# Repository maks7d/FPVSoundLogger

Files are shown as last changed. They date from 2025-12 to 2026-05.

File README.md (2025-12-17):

# FPVSoundLogger
A DIY RP2040-Zero based onboard audio recorder for FPV drones. It uses a MEMS mic and SD card module to capture sound, automatically triggered by Betaflight arming via PinioBox. Recordings match DJI goggles video length for seamless editing. Includes hardware design, MicroPython code, and examples.

###### Enjoy this project or find it useful? Feel free to buy me a coffee ☕ to support its development. 

## Project Background

I first started experimenting with the excellent and promising [OpenIPC](https://github.com/openipc) project, driven by my love for tinkering, hacking, and coding. The idea of building an open FPV video system was incredibly appealing.
But after many tests, the freeze issues and limited range eventually convinced me to switch to DJI for reliable everyday flying.
(But I promise — I’ll come back to OpenIPC!)

The DJI O4 Air Unit provides fantastic onboard video recordings.
But (because there's always a “but”), it still doesn’t record audio. And audio truly adds something special — whether for aggressive FPV flying or even some cinematic flights.

So I wanted a solution that would be simple/lightweight/inexpensive and capable of recording high‑quality audio and perfectly* synchronized with DJI recordings.
This project is the result of that idea.

##### Démo


Play

## Features
- Autonomous module
- Work with [Betaflight](https://github.com/betaflight/betaflight)/[INAV](https://github.com/iNavFlight/inav) 
- Enable/disable recording
- Auto record using arm/disarm trigger
- Audio/video share the same duration*

## Prerequisites

- A flight controller running **[Betaflight](https://github.com/betaflight/betaflight)**/**[INAV](https://github.com/iNavFlight/inav)** with at least two available Pinio outputs
- A transmitter (TX) capable of assigning **AUX channels** (EdgeTX, OpenTX, etc.)
- A stable **3.3V** output on the flight controller and a **common ground**
- A free **switch** or similar to toggle recording modes
- Basic soldering tools for connecting power, ground, and signal wires and plenty of flux — <u>***flux is life***</u>

## How It Works

- Power up the drone — In **Disable** mode module's LED **Red** blinking 🔴
- Use one of your TX switches to **Enable** recording mode — the LED now blinks **Green** 🟢
- **Arm**: the module immediately starts **writing audio data** to the SD card, and the LED now blinks **Blue** 🔵
- **Once disarmed** — whether after a normal end of flight or a dramatic crash — the module **stops recording** and finalizes the audio file with the proper header
- Remove the SD card and retrieve the **WAV file** that matches the exact flight duration
- Import the audio into your favorite video editor and drop it on the timeline — it syncs effortlessly with the DJI footage !
> **⚠️ Fine-tuning tip:** Due to DJI's camera initialization delay after arming, 
> you may need to offset the audio track by **0.5-2 seconds** in your editor. 

**Format:** `rec_XXXX_MM-SS.wav`
- 🔵 **Index (XXXX)**: Auto-incremented counter (0001, 0002, 0003...)
- 🟡 **Duration (MM-SS)**: Recording length in minutes and seconds

FilesDurations

## Architecture / Hardware Overview

### Components

|  | INMP441 | RP2040-Zero | SD Card SPI Module |
| - | :---: | :---: | :---: |
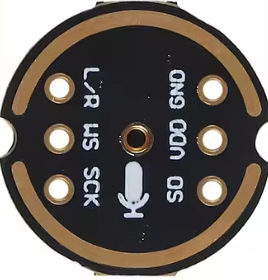
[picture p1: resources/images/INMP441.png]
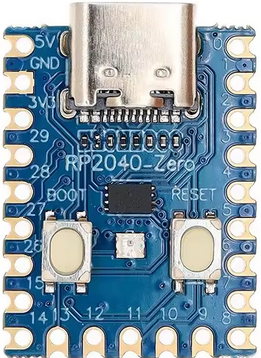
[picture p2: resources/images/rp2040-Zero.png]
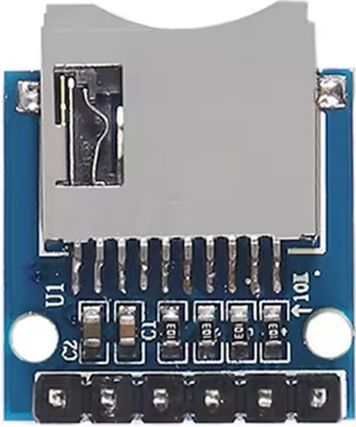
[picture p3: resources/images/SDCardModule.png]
| | |  |  |
| Description | The INMP441 is a compact digital MEMS microphone that outputs audio through an I²S interface.It delivers low‑noise, high‑quality audio capture with a built‑in amplifier and ADC | The Raspberry Pi Pico uses the RP2040 dual‑core ARM Cortex‑M0+ microcontroller running at up to 133 MHz with 264 KB RAM and 2 MB flash.It offers rich connectivity like I²C, SPI, UART, PWM, ADC, and powerful PIO blocks for custom protocols.Compact, low‑cost, and easy to program in **MicroPython** or C/C++.| Micro SD TF Card Memory Shield Module provides an easy way to add microSD storage to microcontrollers.It uses an onboard card socket and level shifting for safe 3.3 V–5 V operation.Ideal for large dataqqsets via SPI. |
| Size | 12x14mm | 18x24.5mm | 18x21mm |
| Weight | 0.36gr | 1.66gr | 1.46gr |
| AliExpress | [INMP441](https://www.aliexpress.com/item/1005007889064664.html?spm=a2g0o.order_list.order_list_main.142.32325e5blt8IZ0) | [RP20240-Zero](https://www.aliexpress.com/item/1005007650325892.html?spm=a2g0o.order_list.order_list_main.147.32325e5blt8IZ0) | [SD TF Module](https://www.aliexpress.com/item/1005005591145849.html?spm=a2g0o.order_list.order_list_main.152.32325e5blt8IZ0) |

### Wiring
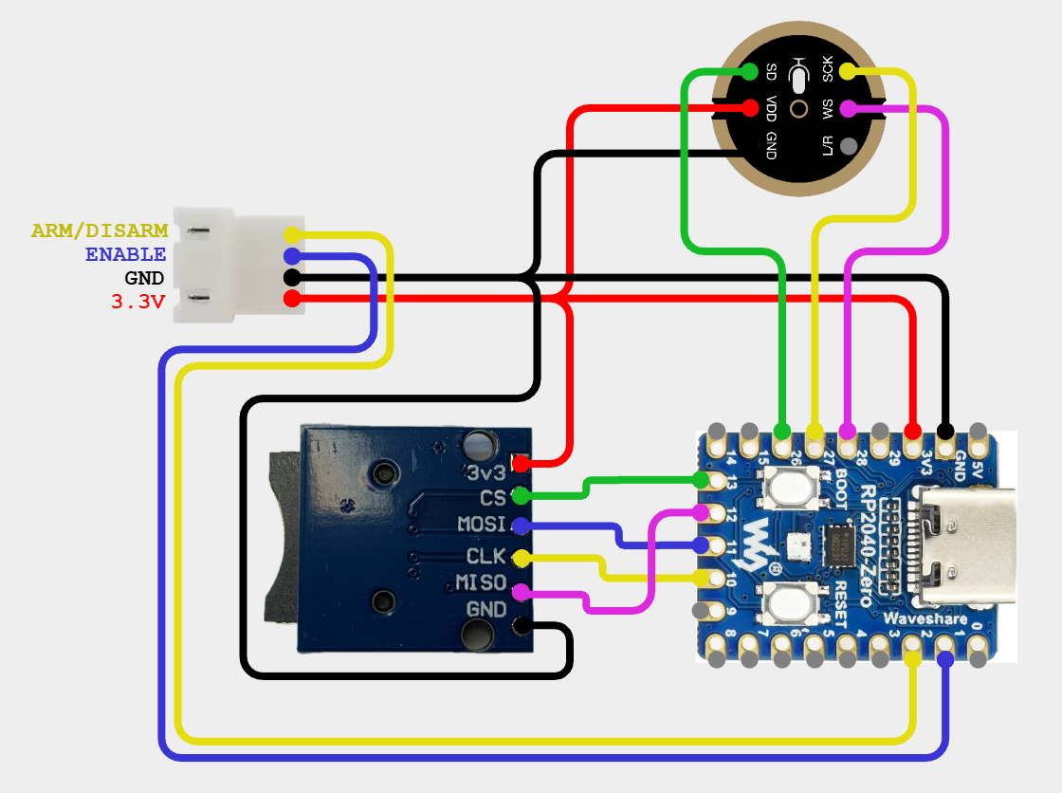
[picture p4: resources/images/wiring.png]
WIRING


### Alternatives
An alternative is to use the FC’s 5 V rail to power the Pi Pico. The SD Card SPI module can convert data signals to 3.3 V levels, allowing it to use the Pi Pico’s 5 V rail. However, according to the [INMP441](resources/datasheet/INMP441.pdf) datasheet, the maximum supply voltage must not exceed 3.63 V, so **you must power it from the Pi Pico’s 3.3 V rail**.

## Build 

In the interest of keeping things lightweight and considering the very low current required for the system to operate, 28‑AWG silicone cable is more than sufficient, and you shouldn’t add more than 1 g to the whole setup.I cut and glued a small foam circle — the kind you find at the bottom of FC/ESC boxes, as dense as possible — to make a windscreen/pop filter.

Be careful not to get any glue into the microphone’s input opening.To keep everything in place, I used a ridiculously heavy piece of heat‑shrink tubing to “thermal‑zipper” the whole thing, along with a bit of hot glue (B7000 is obviously the best option, though hard to find) to secure the small 4‑pin JST connector against the assembly.

In my rough version installed in my Jeno 5", the module weighs about 10 g, but it’s definitely possible to do much better.

A voltage spike can cause parasitic artifacts in the recording. I haven’t tested this yet, but as mentioned in the [INMP441](resources/datasheet/INMP441.pdf) datasheet it is recommended to use a small 0.1 µF ceramic capacitor between VDD and GND.

##### Examples
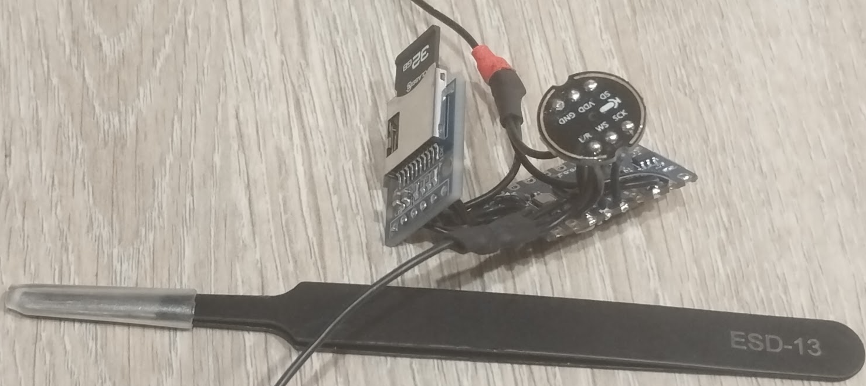
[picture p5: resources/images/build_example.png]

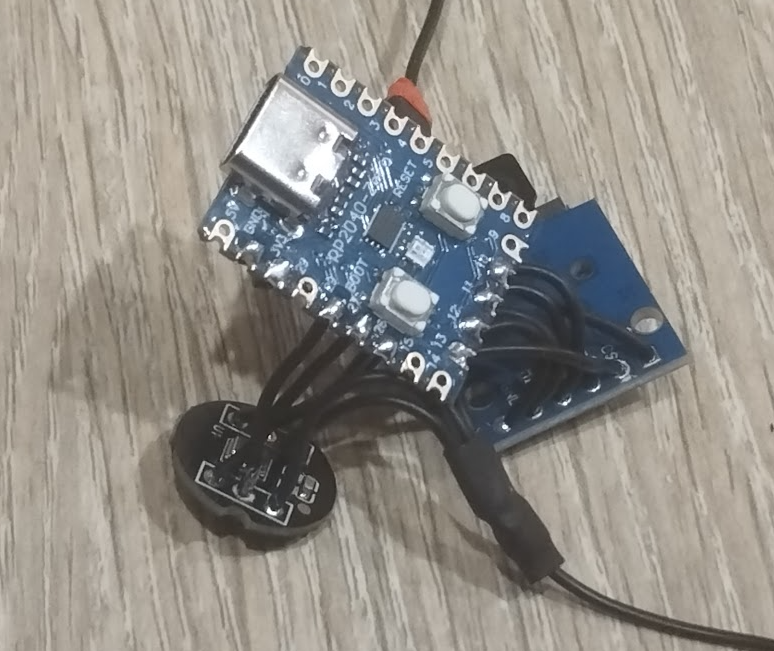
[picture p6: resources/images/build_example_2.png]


## Installation & Configuration

### Pi Pico: Flashing MicroPython on an RP2040 with Thonny

##### 1. Install Thonny
- Download and install [Thonny](https://thonny.org/) from the official website.  
- Open [Thonny](https://thonny.org/).

##### 2. Put the RP2040 board into bootloader mode
- Plug in the board **while holding the BOOTSEL button**.  
- Release the button once connected: the board should appear as a USB drive named **RPI-RP2**.

##### 3. Install MicroPython from [Thonny](https://thonny.org/)
- In Thonny, go to:  
  **Tools → Options… → Interpreter**  
- Select:  
  **MicroPython (Raspberry Pi Pico / RP2040)**  
- Click **Install or update MicroPython**.  
- Select your **RPI-RP2** device.  
- Start the installation.

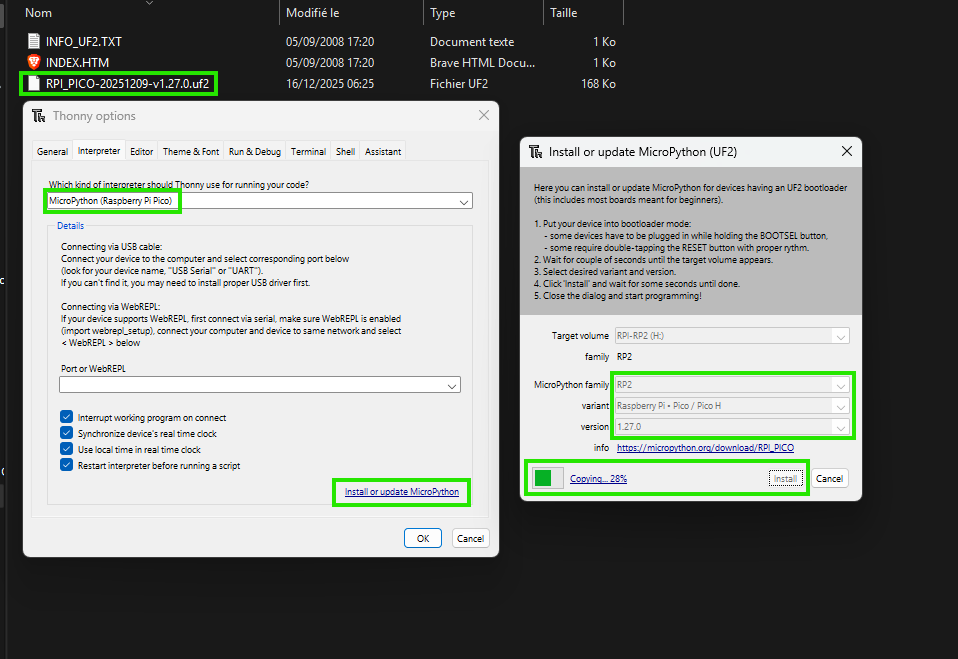
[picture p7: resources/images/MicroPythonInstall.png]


##### 4. Automatic restart
The board will reboot with MicroPython installed.  
[Thonny](https://thonny.org/) should now display a `>>>` prompt.

##### 5. Quick test
Type:

```python
print(f"WE ARE {'fpv'.upper()}")
```

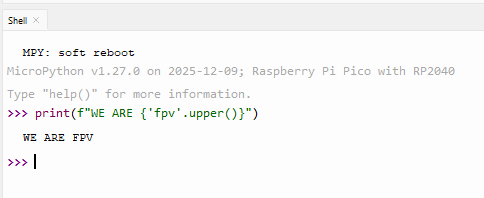
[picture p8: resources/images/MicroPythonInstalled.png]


##### 6. Project files to upload
```
├── main.py                    # Main application (auto-runs on boot)
   └── lib/
       ├── sdcard.py              # SD card driver
       └── fpv_sound_logger.py    # Core logger class
```

- In Thonny, go to **View > Files**
- In your computer's file panel (left side), navigate to your project folder
- Select the `lib` folder
- Right-click → **"Upload to /"**
- Then select `main.py`
- Right-click → **"Upload to /"**
- Thonny will upload the entire structure automatically

> **Note:** This method preserves the folder structure. The `lib` folder and its contents will be uploaded correctly.
<p align="left">
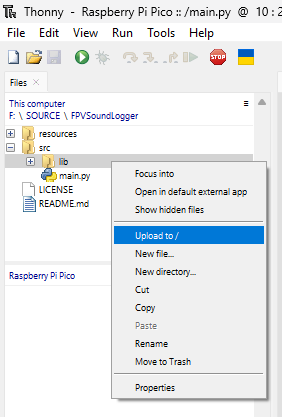
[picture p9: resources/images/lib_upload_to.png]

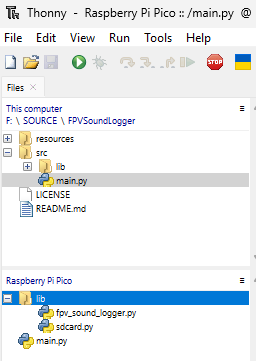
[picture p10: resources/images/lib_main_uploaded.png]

</p>

### TX && Betaflight configuration

All you need to know about Betaflight's Pinio && PinioBox can be found [here](https://www.betaflight.com/docs/wiki/guides/current/Pinio-and-PinioBox), I also got some excellent advice from Betaflight’s [official discord](https://discord.betaflight.com/)

- You'll need to configure AUX channel on your TX to Enable/Disable recording

    > I configured it to use the center position of an three-position switch mapped to AUX6 on my Radiomaster Pocket running on EdgeTX.

- Provide a **common ground** from the flight controller to the module, along with a clean **3.3V** or [5V supply](#Alternatives)

    > On my JHEMCU GF20F722, I used the 3.3V rail that was originally intended for a DSM receiver.

- Configure your flight controller’s Pinio outputs using CLI to deliver the required logic levels:

    - One Pinio controls record enable/disable

    - The second Pinio follows the arm/disarm sequence to automatically start and stop recording.

    > [...]
    > 
    > resource pinio 1 B10          # remap RX3 pad
    > 
    > resource pinio 2 B11          # remap TX3 pad
    > 
    > set pinio_config = 1,129,1,1  # High level for _pinio 1_ and inverted for _pinio 2_
    > 
    > set pinio_box = 40,0,255,255  # ID 40 mean BOXUSER1 and ID 0 Arm/Disarms

- Configure a new mode for USER1

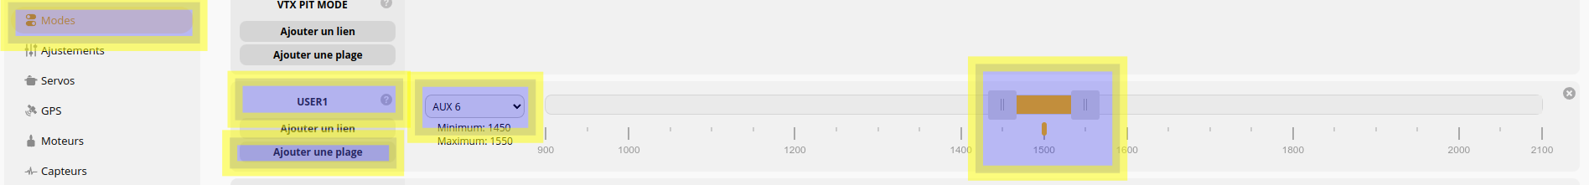
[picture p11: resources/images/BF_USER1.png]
test


### For testing purposes

Even if the 3.3 V or 5 V rail used to power the recorder is active while [Betaflight](https://github.com/betaflight/betaflight) is connected via USB, you still won’t be able to start the recording. The [Betaflight](https://github.com/betaflight/betaflight) safety flags will prevent the drone from arming.

Because of this, even with the ***MOTOR_STOP*** option enabled in the Motors tab, the brushless motors may still start spinning. As a result, you will always have motor or propeller noise in your recordings — never any silence. And if you need to speak into the microphone, **be careful**… or make sure to shout loud enough! ^^

###### TODO
A lot ...!?

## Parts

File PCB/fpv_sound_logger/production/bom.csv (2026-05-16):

Designator | Footprint | Quantity | Value | LCSC Part #
C1, C10, C11, C14, C2, C3, C4, C5, C6, C7 | 0603 | 10 | 100n
C12, C13 | 0603 | 2 | 15p
C15, C17 | 0603 | 2 | 10u
C19, C8, C9 | 0603 | 3 | 1u
CN1 | CONN-SMD_4P-P1.00_SM04B-SRSS-TB-LF-SN | 1 | SM04B-SRSS-TB(LF)(SN)
D1, D2 | SOT95P280X145-5M | 2 | MAX40203AUK+T
IC1 | SOIC127P790X216-8N | 1 | W25Q128JVSIQ
J2 | CUI_MSD-4-A | 1 | MSD-4-A
LED1 | INS66TFT5R5G5B | 1 | IN-S66TFT5R5G5B
LED2 | LED_LTST-C171_LTO-M | 1 | LTST-C171KRKT
MIC1 | MIC-TH_BD6.0-P1.90-D0.4-L-FD_GMI6050P-2CXXDB | 1 | ~
R1, R2 | 0603 | 2 | 27
R10, R11, R13, R3, R9 | 0603 | 5 | 1k
R12, R17, R18, R19, R20 | 0603 | 5 | 10k
R14 | 0603 | 1 | 2k2
R5, R6 | 0603 | 2 | 5k1
S1, S2 | B3U-1000P | 2 | B3U-1000P
U3 | SOT95P280X145-5N | 1 | TLV75533PDBVR
U4 | QFN40P700X700X90-57N | 1 | SC0914_13_
USB1 | USB-C-SMD_TYPE-C-6PIN-2MD-073 | 1 | TYPE-C 16PIN 2MD(073)
Y1 | ABM8272T3 | 1 | ABM8-272-T3

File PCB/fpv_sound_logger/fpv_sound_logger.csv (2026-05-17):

Reference | Qty | Value | DNP | Exclude from BOM | Exclude from Board | Footprint | Datasheet | Manufacturer_Part_Number | Supplier | Supplier Part | Manufacturer
C1,C2,C3,C4,C5,C6,C7,C10,C11,C14 | 10 | 100n |  |  |  | Capacitor_SMD:C_0603_1608Metric |  | CL10B104KB8NNNC | LCSC | C1591 | Samsung Electro-Mechanics
C8,C9,C19 | 3 | 1u |  |  |  | Capacitor_SMD:C_0603_1608Metric |  | CL10B105KA8NNNC | LCSC | C29936 | Samsung Electro-Mechanics
C12,C13 | 2 | 15p |  |  |  | Capacitor_SMD:C_0603_1608Metric |  | CL10C150JB8NNNC | LCSC | C1644 | Samsung Electro-Mechanics
C15,C17 | 2 | 10u |  |  |  | Capacitor_SMD:C_0603_1608Metric |  | CL10A106MQ8NNNC | LCSC | C1691 | Samsung Electro-Mechanics
CN1 | 1 | SM04B-SRSS-TB(LF)(SN) |  |  |  | fpv_sound_logger:CONN-SMD_4P-P1.00_SM04B-SRSS-TB-LF-SN |  | SM04B-SRSS-TB(LF)(SN) | LCSC | C160404 | JST
D1,D2 | 2 | MAX40203AUK+T |  |  |  | fpv_sound_logger:SOT95P280X145-5M |  | MAX40203AUK+T | LCSC | C2653639 | MAXIM
IC1 | 1 | W25Q128JVSIQ |  |  |  | fpv_sound_logger:SOIC127P790X216-8N |  | W25Q128JVSIQ | LCSC | C113767 | Winbond
J2 | 1 | MSD-4-A |  |  |  | fpv_sound_logger:CUI_MSD-4-A |  | MSD-4-A | LCSC | C22367949 | CUI Devices
LED1 | 1 | IN-S66TFT5R5G5B |  |  |  | fpv_sound_logger:INS66TFT5R5G5B |  | 19-337/R6GHBHC-A01/2T | LCSC | C264519 | EVERLIGHT
LED2 | 1 | LTST-C171KRKT |  |  |  | fpv_sound_logger:LED_LTST-C171_LTO-M |  | LTST-C171KRKT | LCSC | C284871 | LITEON
MIC1 | 1 |  |  |  |  | fpv_sound_logger:MIC-TH_BD6.0-P1.90-D0.4-L-FD_GMI6050P-2CXXDB | https://atta.szlcsc.com/upload/public/pdf/source/20180613/C233951_CF3F103FE3546E5F8FCD1BC0597FF08F.pdf | GMI6050P-36db | LCSC | C233939 | INGHAi
R1,R2 | 2 | 27 |  |  |  | Resistor_SMD:R_0603_1608Metric |  | ERJ3EKF27R0V | LCSC | C403127 | PANASONIC
R3,R9,R10,R11,R13 | 5 | 1k |  |  |  | Resistor_SMD:R_0603_1608Metric |  | ERJ3EKF1001V | LCSC | C118155 | PANASONIC
R5,R6 | 2 | 5k1 |  |  |  | Resistor_SMD:R_0603_1608Metric |  | ERA3AEB512V | LCSC | ERA3AEB512V | PANASONIC
R12,R17,R18,R19,R20 | 5 | 10k |  |  |  | Resistor_SMD:R_0603_1608Metric |  | ERJUP3F1002V | LCSC | ERJUP3F1002V | PANASONIC
R14 | 1 | 2k2 |  |  |  | Resistor_SMD:R_0603_1608Metric |  | ERJ3EKF1001V | LCSC | C118155 | PANASONIC
S1,S2 | 2 | B3U-1000P |  |  |  | fpv_sound_logger:B3U-1000P | https://www.omron.com/ecb/products/pdf/en-b3u.pdf | B3U-1000P | LCSC | C231329 | OMRON
TP1,TP2,TP3,TP4 | 4 | TestPoint | DNP |  |  | TestPoint:TestPoint_Pad_D1.0mm
U3 | 1 | TLV75533PDBVR |  |  |  | fpv_sound_logger:SOT95P280X145-5N |  | TLV75533PDBVR | LCSC | C404027 | TI
U4 | 1 | SC0914_13_ |  |  |  | fpv_sound_logger:QFN40P700X700X90-57N |  | RP2040 | LCSC | C2040 | Raspberry Pi
USB1 | 1 | TYPE-C 16PIN 2MD(073) |  |  |  | fpv_sound_logger:USB-C-SMD_TYPE-C-6PIN-2MD-073 | https://item.szlcsc.com/datasheet/TYPE-C%252016PIN%25202MD(073)/2901843.html | TYPE-C 16PIN 2MD(073) | LCSC | C2765186 | SHOU HAN
Y1 | 1 | ABM8-272-T3 |  |  |  | fpv_sound_logger:ABM8272T3 | https://abracon.com/datasheets/ABM8-272-T3.pdf | ABM8-272-T3 | LCSC | C20625731 | ABRACON

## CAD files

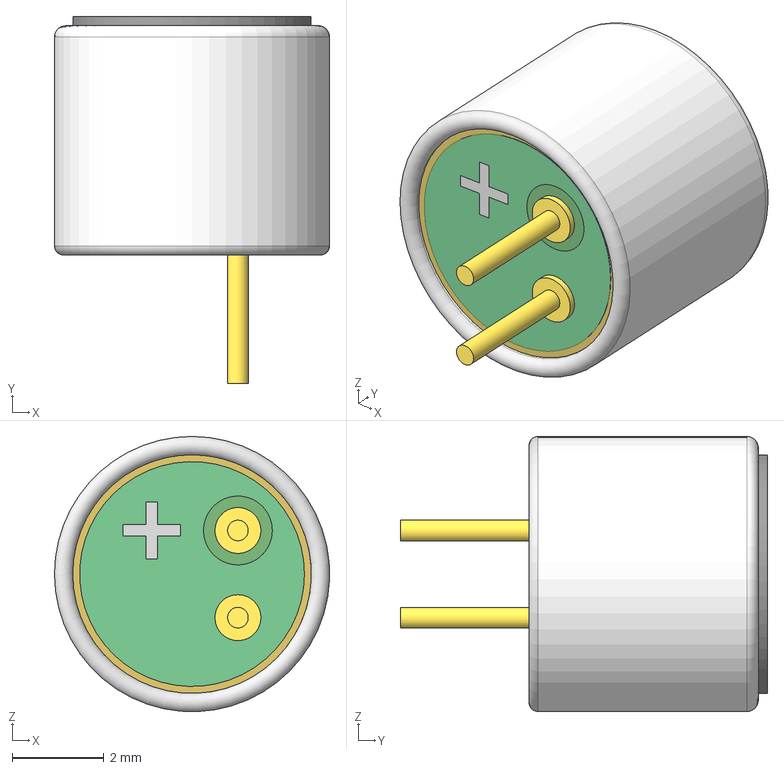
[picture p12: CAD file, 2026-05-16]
PCB/3D/POM-5038P-C3310-R.STEP
6.00 x 8.00 x 6.00 mm

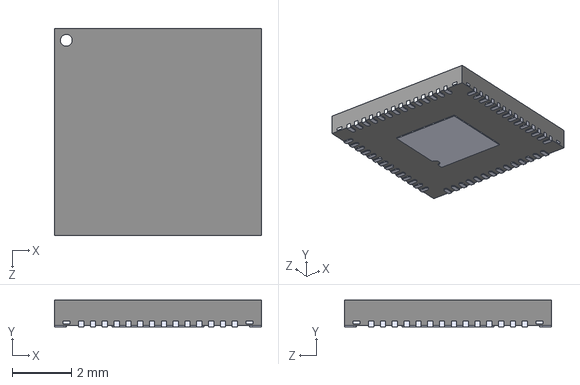
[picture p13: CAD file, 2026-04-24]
PCB/3D/SC0914_13_.step
7.00 x 0.9 x 7.00 mm

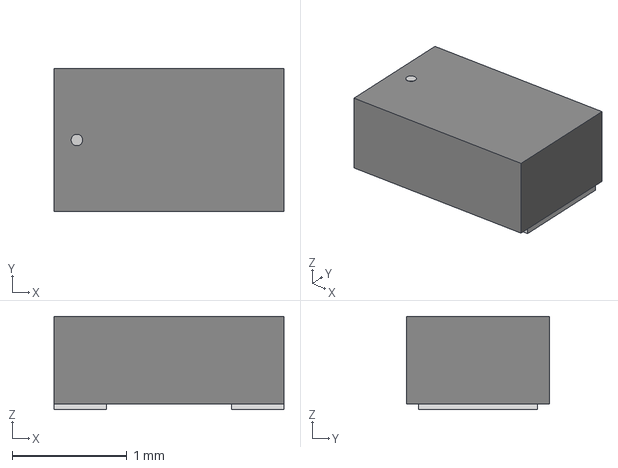
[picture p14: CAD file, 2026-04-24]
PCB/3D/LED_LTST-C171_LTO.step
2.01 x 1.24 x 0.815 mm

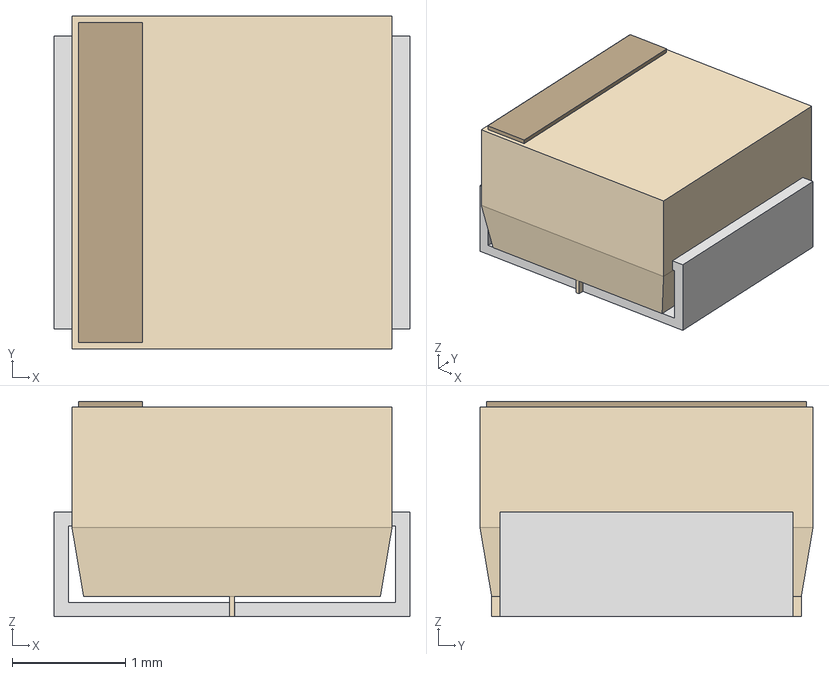
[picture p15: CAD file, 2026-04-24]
PCB/3D/LED_X01-GS08_VIS.step
3.15 x 2.95 x 1.91 mm

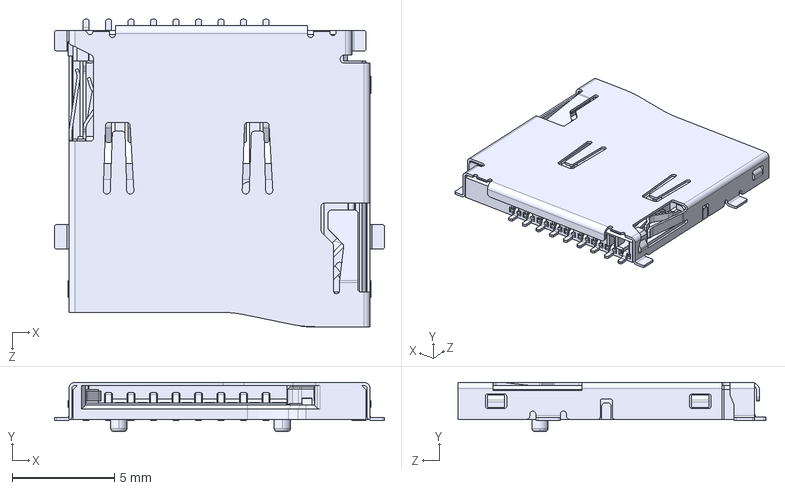
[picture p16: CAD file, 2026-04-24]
PCB/3D/MSD-4-A.step
16.1 x 2.40 x 15.0 mm

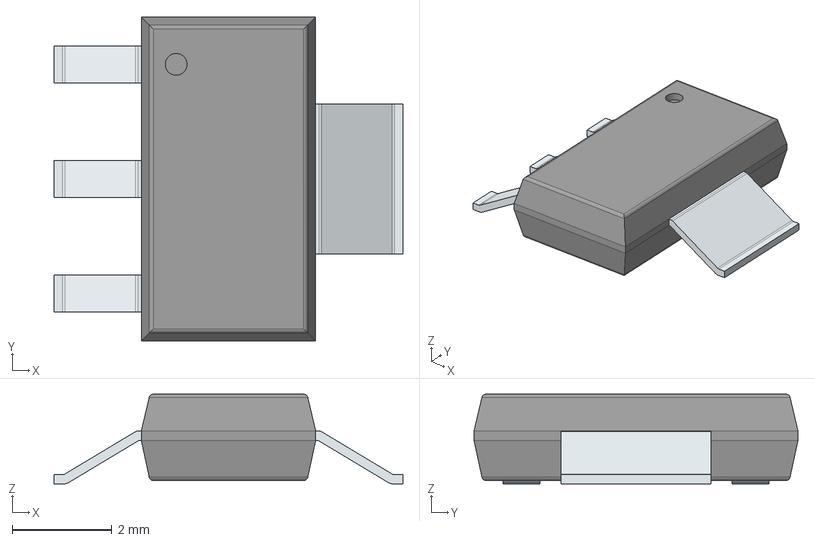
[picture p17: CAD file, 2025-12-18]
PCB/3D/NCP1117ST33T3G.stp
7.00 x 6.50 x 1.80 mm
PinsArrayL
FilletPinR

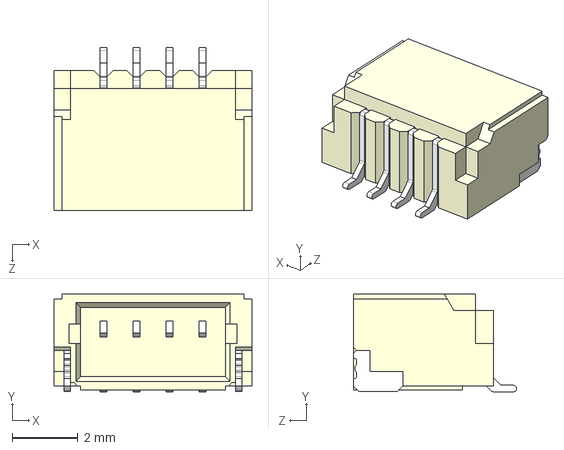
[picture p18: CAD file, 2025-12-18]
PCB/3D/SM04B-SRSS-TB--3DModel-STEP-269445.STEP
6.00 x 2.96 x 4.95 mm

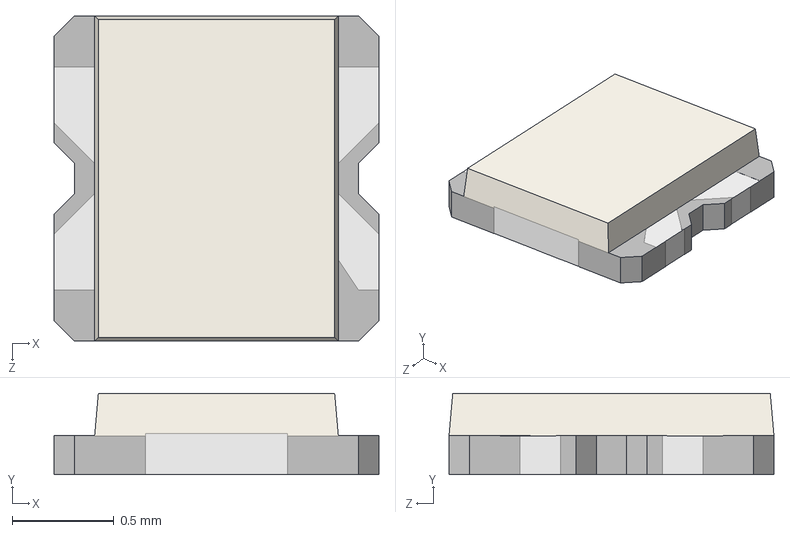
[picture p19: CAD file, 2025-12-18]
PCB/3D/IN-S66TFT5R5G5B.stp
1.60 x 0.401 x 1.60 mm

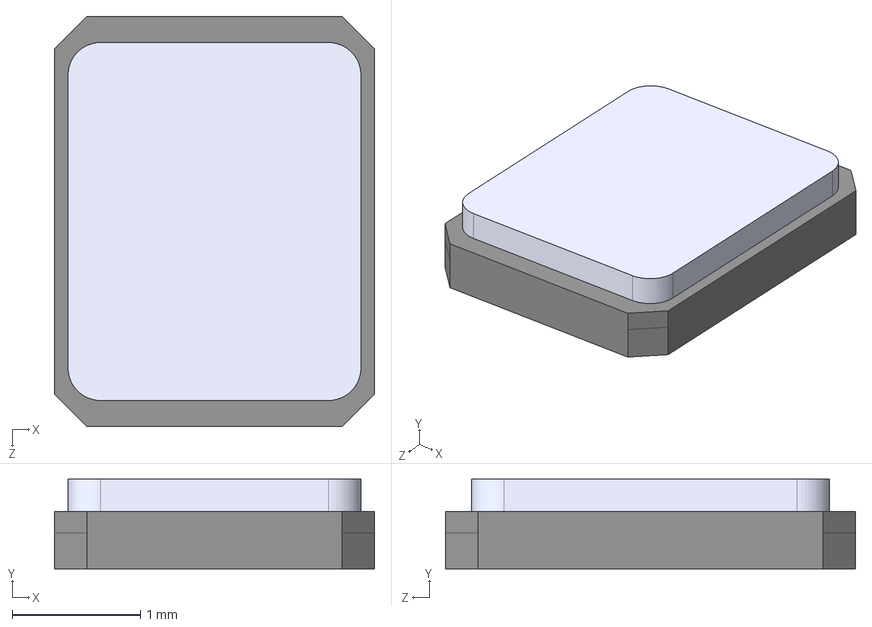
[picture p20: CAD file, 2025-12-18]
PCB/3D/ABM8-272-T3.STEP
2.50 x 0.7 x 3.20 mm

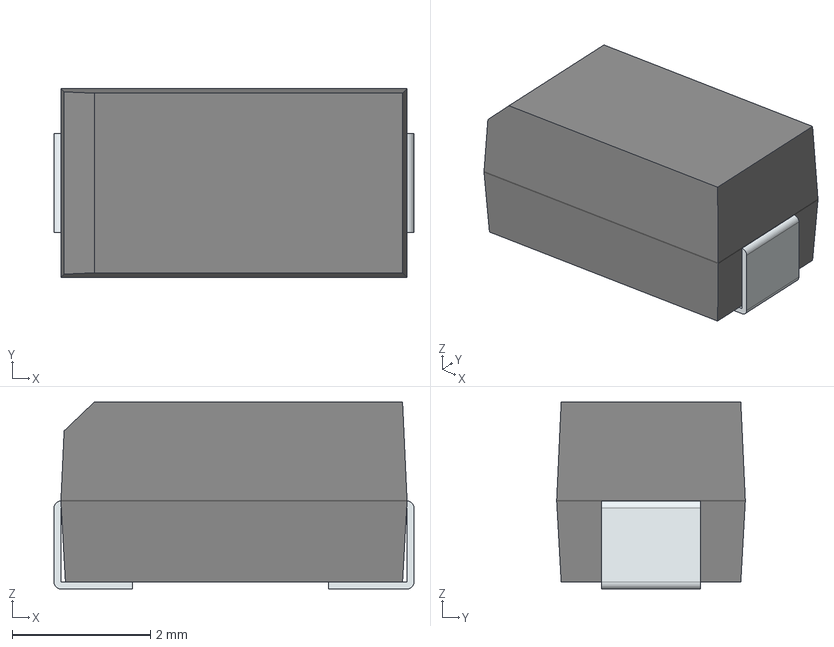
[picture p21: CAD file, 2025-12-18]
PCB/3D/SS14.stp
5.20 x 2.73 x 2.70 mm
FilletPin1
FilletPin2

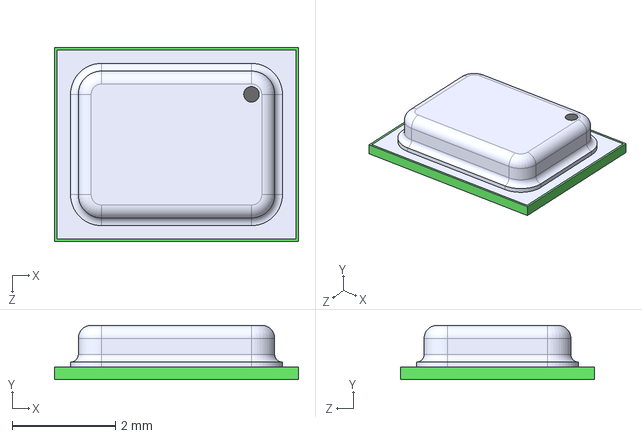
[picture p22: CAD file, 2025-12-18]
PCB/3D/INMP441ACEZ-R7--3DModel-STEP-56544.STEP
4.72 x 1.05 x 3.76 mm

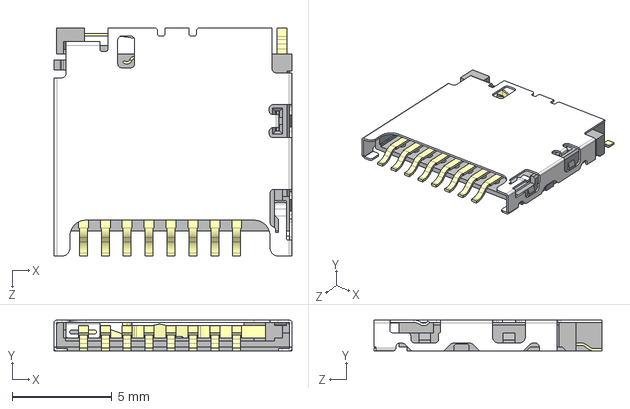
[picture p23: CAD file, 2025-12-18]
PCB/3D/DM3D-SF.stp
12.0 x 1.55 x 11.4 mm

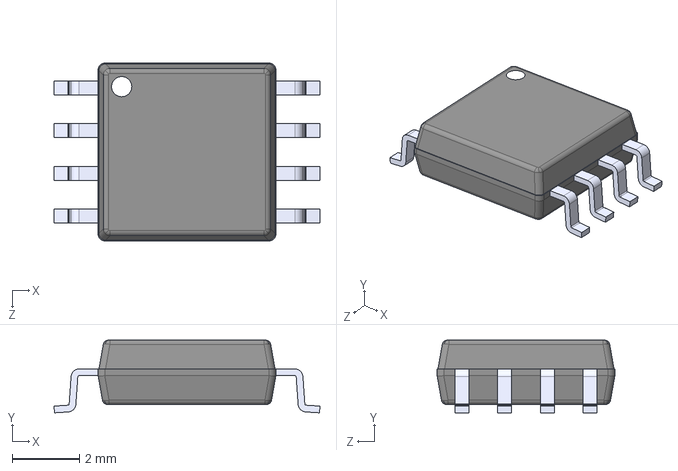
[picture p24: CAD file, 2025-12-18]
PCB/3D/W25Q128JVSIQ.STEP
7.90 x 2.16 x 5.28 mm

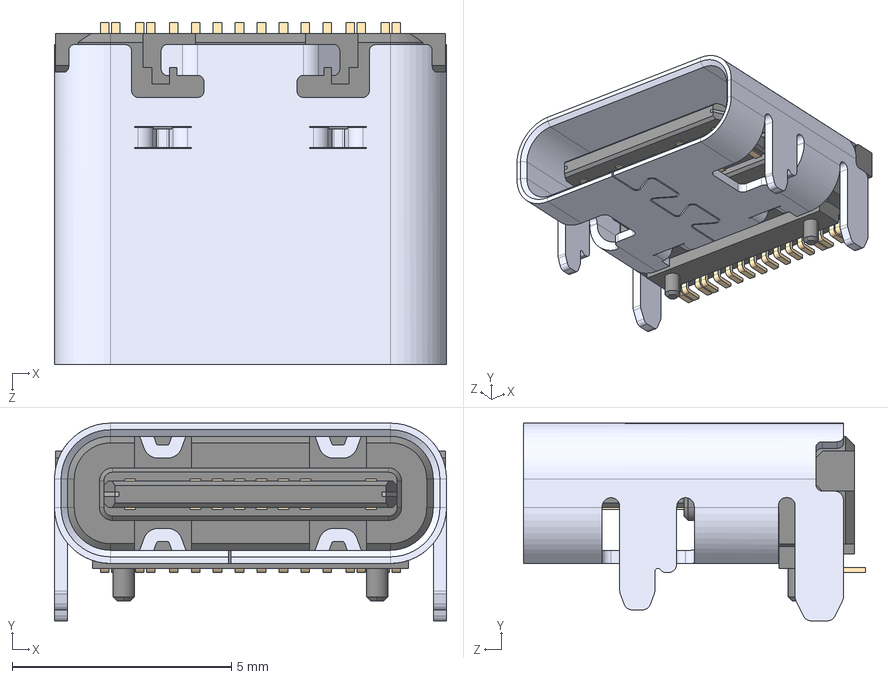
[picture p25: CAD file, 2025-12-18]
PCB/3D/USB-C_standard.STEP
8.94 x 4.51 x 7.81 mm

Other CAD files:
PCB/3D/B3U-1000P.stp
PCB/3D/TLV75533PDBVR.step
PCB/3D/MAX40203AUK+T.stp

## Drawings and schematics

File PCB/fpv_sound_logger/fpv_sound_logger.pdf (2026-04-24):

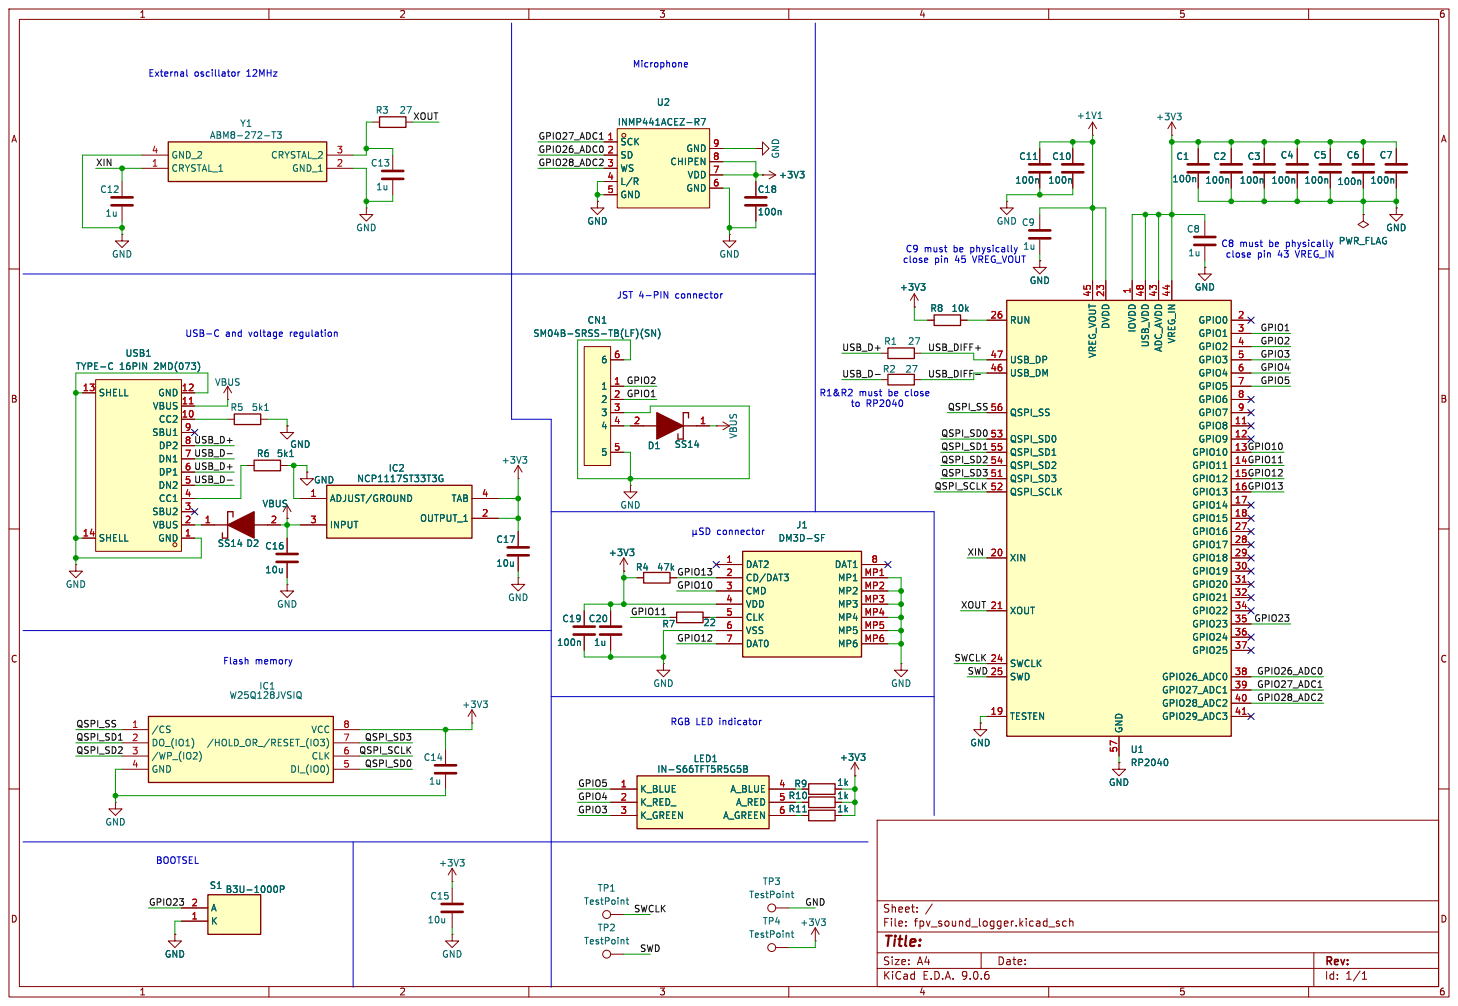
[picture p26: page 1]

5 CN1 SM04B-SRSS-TB(LF)(SN) +3V3 C20

1u +3V3 CN1 SM04B-SRSS-TB(LF)(SN) 6

close pin 45 VREG_VOUT USB-C and voltage regulation

þÿµSDconnector Flash memory

Id: 1/1 Title: File: fpv_sound_logger.kicad_sch Sheet: / GND

RGB LED indicator BOOTSEL

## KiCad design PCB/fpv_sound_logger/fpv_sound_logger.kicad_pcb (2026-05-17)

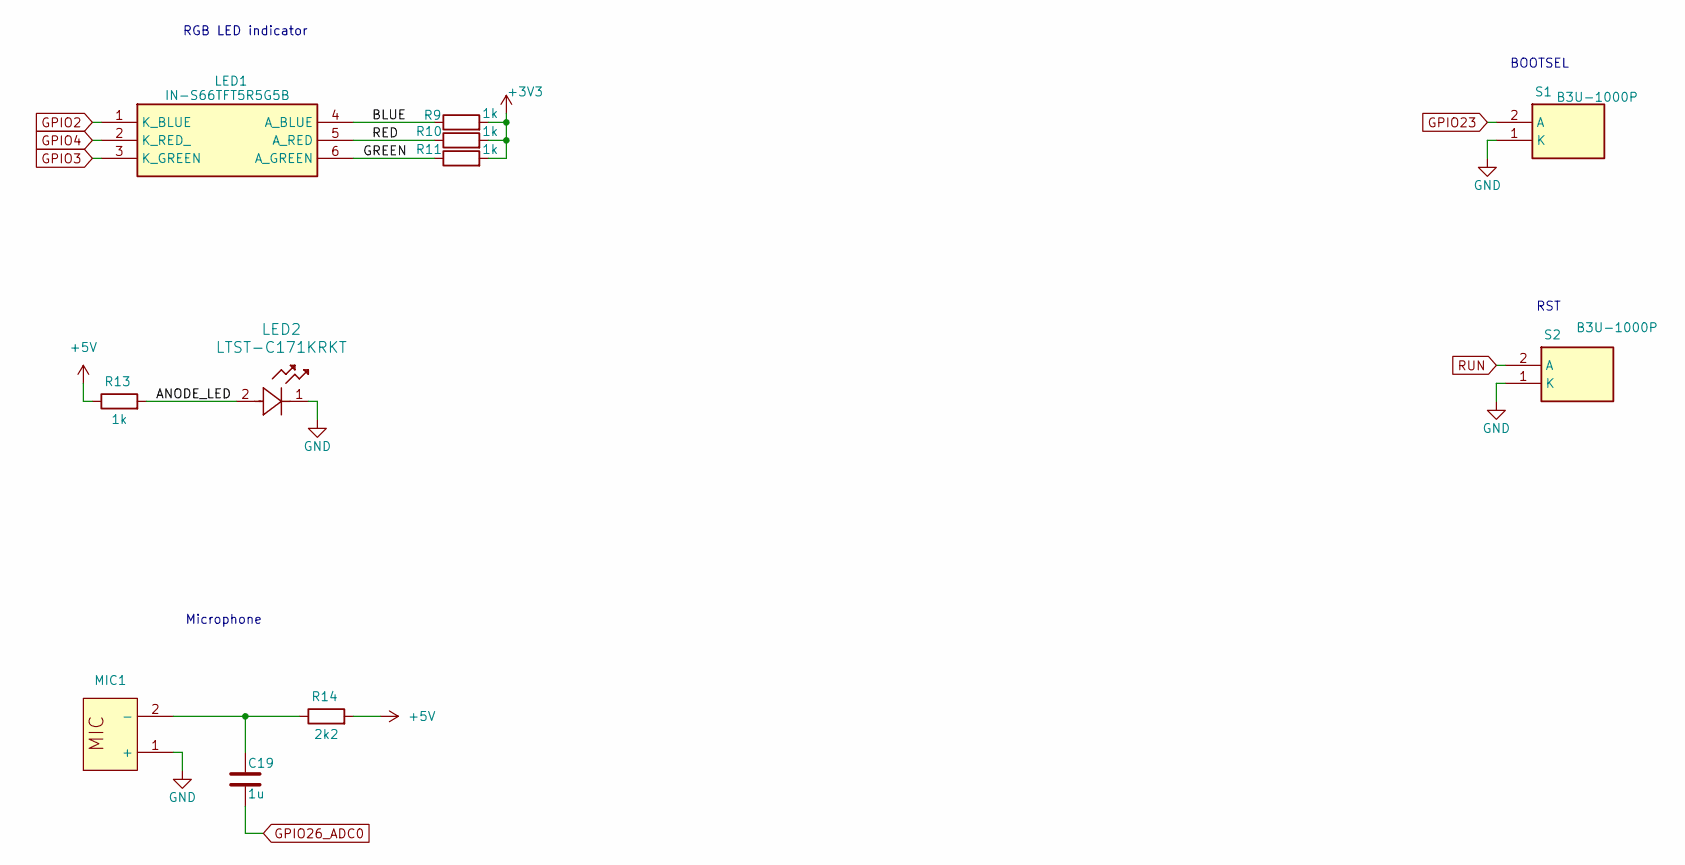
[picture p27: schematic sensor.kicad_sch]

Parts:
C19: 1u; C_0603_1608Metric; Manufacturer_Part_Number CL10B105KA8NNNC
LED1: IN-S66TFT5R5G5B; INS66TFT5R5G5B; Mouser Part Number 743-IN-S66TFT5R5G5B
LED2: LTST-C171KRKT; LED_LTST-C171_LTO-M; Manufacturer_Part_Number LTST-C171KRKT
MIC1: MIC-TH_BD6.0-P1.90-D0.4-L-FD_GMI6050P-2CXXDB; Manufacturer Part GMI6050P-36db; LCSC Part Name 全指向φ6.0*5.0mm 1.5V-10V 灵敏度-36db 低阻抗 针脚
R9, R10, R11, R13: 1k; R_0603_1608Metric; Manufacturer_Part_Number ERJ3EKF1001V
R14: 2k2; R_0603_1608Metric; Manufacturer_Part_Number ERJ3EKF1001V
S1, S2: B3U-1000P; Mouser Part Number 653-B3U-1000P

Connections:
+3V3: R9.2, R10.2, R11.2; also elsewhere on the board
+5V: R13.1, R14.2; also elsewhere on the board
/sensor/ANODE_LED: LED2.2, R13.2
/sensor/BLUE: LED1.4 (A_BLUE), R9.1
/sensor/GREEN: LED1.6 (A_GREEN), R11.1
/sensor/RED: LED1.5 (A_RED), R10.1
GND: LED2.1, MIC1.1 (+), S1.1 (K), S2.1 (K); also elsewhere on the board
GPIO2: LED1.1 (K_BLUE); also elsewhere on the board
GPIO3: LED1.3 (K_GREEN); also elsewhere on the board
GPIO4: LED1.2 (K_RED_); also elsewhere on the board
GPIO23: S1.2 (A); also elsewhere on the board
GPIO26_ADC0: C19.2; also elsewhere on the board
unnamed: C19.1, MIC1.2 (-), R14.1
RUN: S2.2 (A); also elsewhere on the board

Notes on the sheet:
RST
RGB LED indicator
BOOTSEL
Microphone

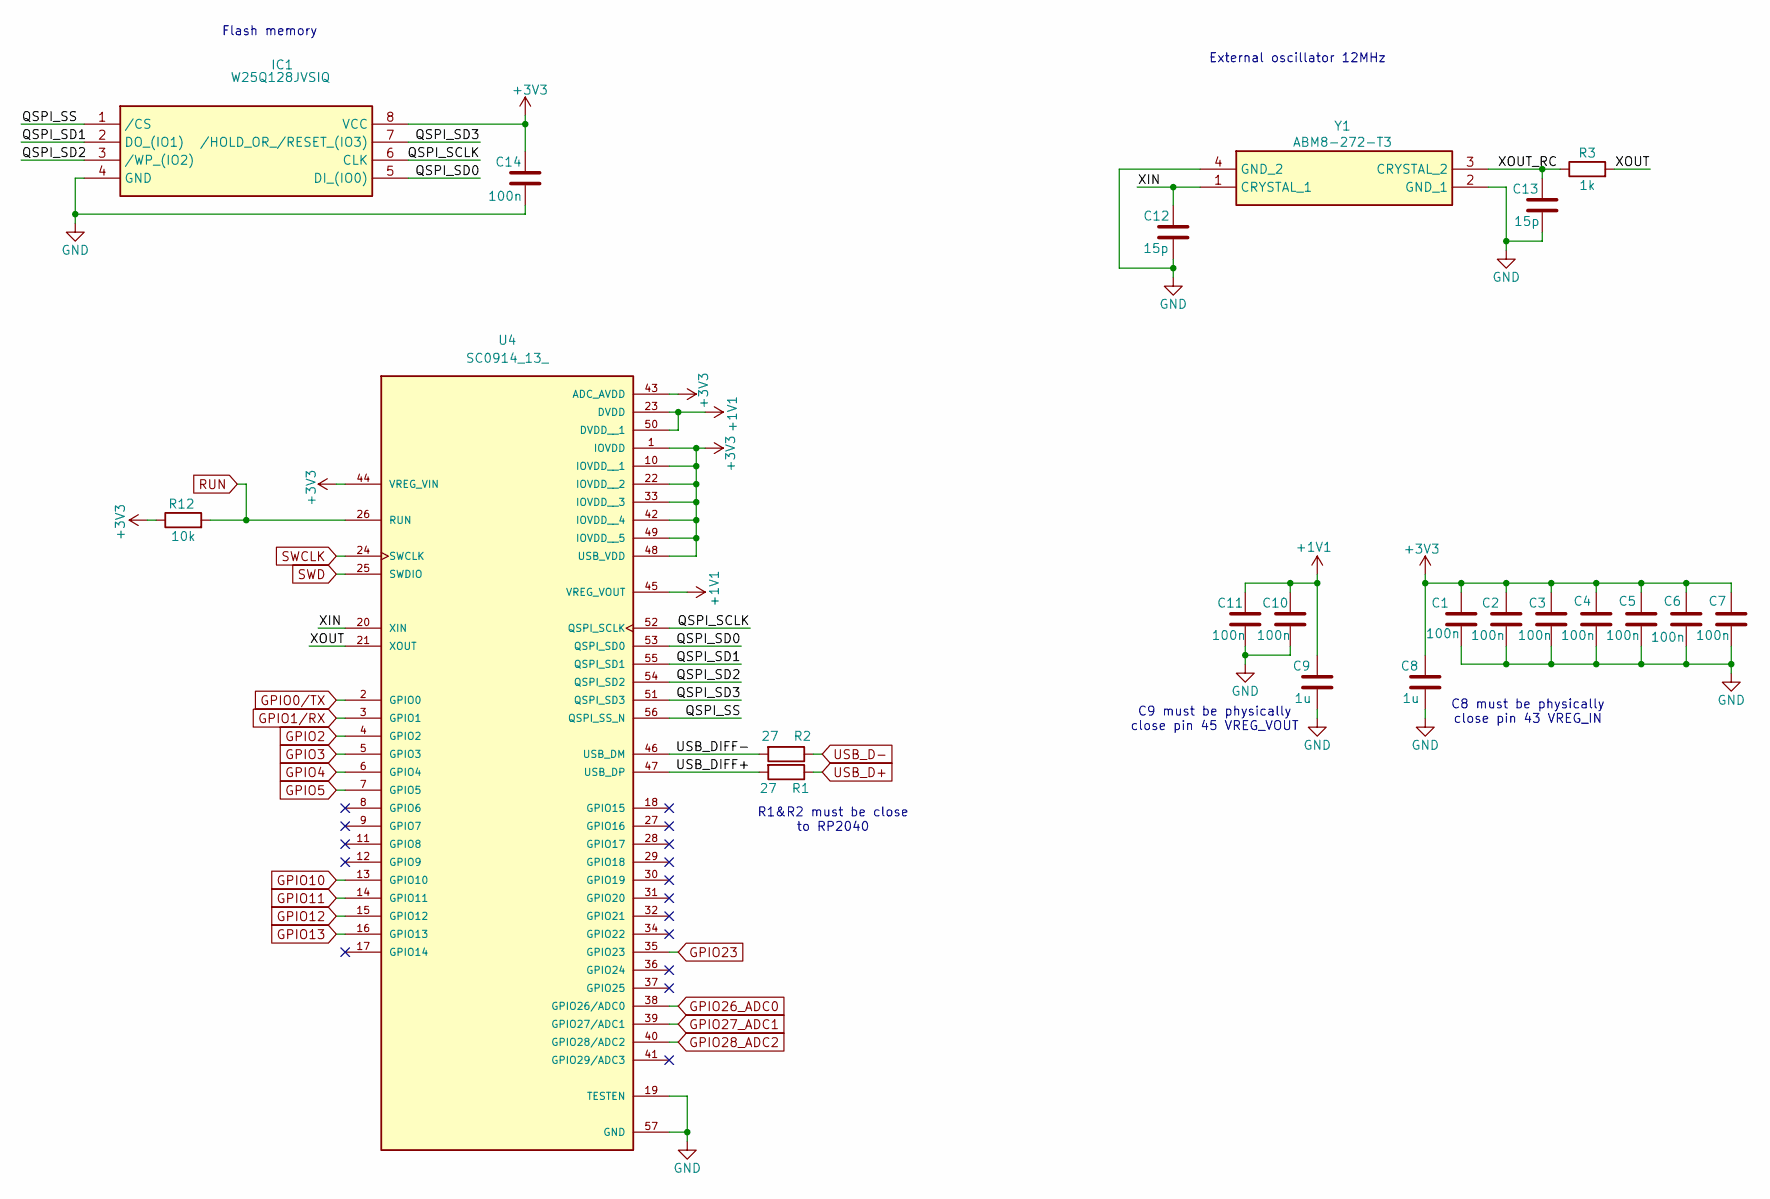
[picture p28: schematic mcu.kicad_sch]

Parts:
C1, C2, C3, C4, C5, C6, C7, C10, C11, C14: 100n; C_0603_1608Metric; Manufacturer_Part_Number CL10B104KB8NNNC
C8, C9: 1u; C_0603_1608Metric; Manufacturer_Part_Number CL10B105KA8NNNC
C12, C13: 15p; C_0603_1608Metric; Manufacturer_Part_Number CL10C150JB8NNNC
IC1: W25Q128JVSIQ; SOIC127P790X216-8N; Mouser Part Number 454-W25Q128JVSIQ
R1, R2: 27; R_0603_1608Metric; Manufacturer_Part_Number ERJ3EKF27R0V
R3: 1k; R_0603_1608Metric; Manufacturer_Part_Number ERJ3EKF1001V
R12: 10k; R_0603_1608Metric; Manufacturer_Part_Number ERJUP3F1002V
U4: SC0914_13_; QFN40P700X700X90-57N; PARTREV 2.2
Y1: ABM8-272-T3; ABM8272T3; Mouser Part Number 815-ABM8-272-T3

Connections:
+1V1: C9.1, C10.1, C11.1, U4.23 (DVDD), U4.45 (VREG_VOUT), U4.50 (DVDD__1)
+3V3: C1.1, C2.1, C3.1, C4.1, C5.1, C6.1, C7.1, C8.1, C14.1, IC1.8 (VCC), R12.1, U4.1 (IOVDD), U4.10 (IOVDD__1), U4.22 (IOVDD__2), U4.33 (IOVDD__3), U4.42 (IOVDD__4), U4.43 (ADC_AVDD), U4.44 (VREG_VIN), U4.48 (USB_VDD), U4.49 (IOVDD__5); also elsewhere on the board
/MCU/QSPI_SCLK: IC1.6 (CLK), U4.52 (QSPI_SCLK)
/MCU/QSPI_SD0: IC1.5 (DI_(IO0)), U4.53 (QSPI_SD0)
/MCU/QSPI_SD1: IC1.2 (DO_(IO1)), U4.55 (QSPI_SD1)
/MCU/QSPI_SD2: IC1.3 (/WP_(IO2)), U4.54 (QSPI_SD2)
/MCU/QSPI_SD3: IC1.7 (/HOLD_OR_/RESET_(IO3)), U4.51 (QSPI_SD3)
/MCU/QSPI_SS: IC1.1 (/CS), U4.56 (QSPI_SS_N)
/MCU/USB_DIFF+: R1.2, U4.47 (USB_DP)
/MCU/USB_DIFF-: R2.2, U4.46 (USB_DM)
/MCU/XIN: C12.1, U4.20 (XIN), Y1.1 (CRYSTAL_1)
/MCU/XOUT: R3.2, U4.21 (XOUT)
/MCU/XOUT_RC: C13.1, R3.1, Y1.3 (CRYSTAL_2)
GND: C1.2, C2.2, C3.2, C4.2, C5.2, C6.2, C7.2, C8.2, C9.2, C10.2, C11.2, C12.2, C13.2, C14.2, IC1.4 (GND), U4.19 (TESTEN), U4.57 (GND), Y1.2 (GND_1), Y1.4 (GND_2); also elsewhere on the board
GPIO0/TX: U4.2 (GPIO0); also elsewhere on the board
GPIO1/RX: U4.3 (GPIO1); also elsewhere on the board
GPIO2: U4.4 (GPIO2); also elsewhere on the board
GPIO3: U4.5 (GPIO3); also elsewhere on the board
GPIO4: U4.6 (GPIO4); also elsewhere on the board
GPIO5: U4.7 (GPIO5)
GPIO10: U4.13 (GPIO10); also elsewhere on the board
GPIO11: U4.14 (GPIO11); also elsewhere on the board
GPIO12: U4.15 (GPIO12); also elsewhere on the board
GPIO13: U4.16 (GPIO13); also elsewhere on the board
GPIO23: U4.35 (GPIO23); also elsewhere on the board
GPIO26_ADC0: U4.38 (GPIO26/ADC0); also elsewhere on the board
GPIO27_ADC1: U4.39 (GPIO27/ADC1)
GPIO28_ADC2: U4.40 (GPIO28/ADC2)
RUN: R12.2, U4.26 (RUN); also elsewhere on the board
SWCLK: U4.24 (SWCLK); also elsewhere on the board
SWD: U4.25 (SWDIO); also elsewhere on the board
USB_D+: R1.1; also elsewhere on the board
USB_D-: R2.1; also elsewhere on the board

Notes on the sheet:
External oscillator 12MHz
C9 must be physically close pin 45 VREG_VOUT
R1&R2 must be close to RP2040
C8 must be physically close pin 43 VREG_IN
Flash memory

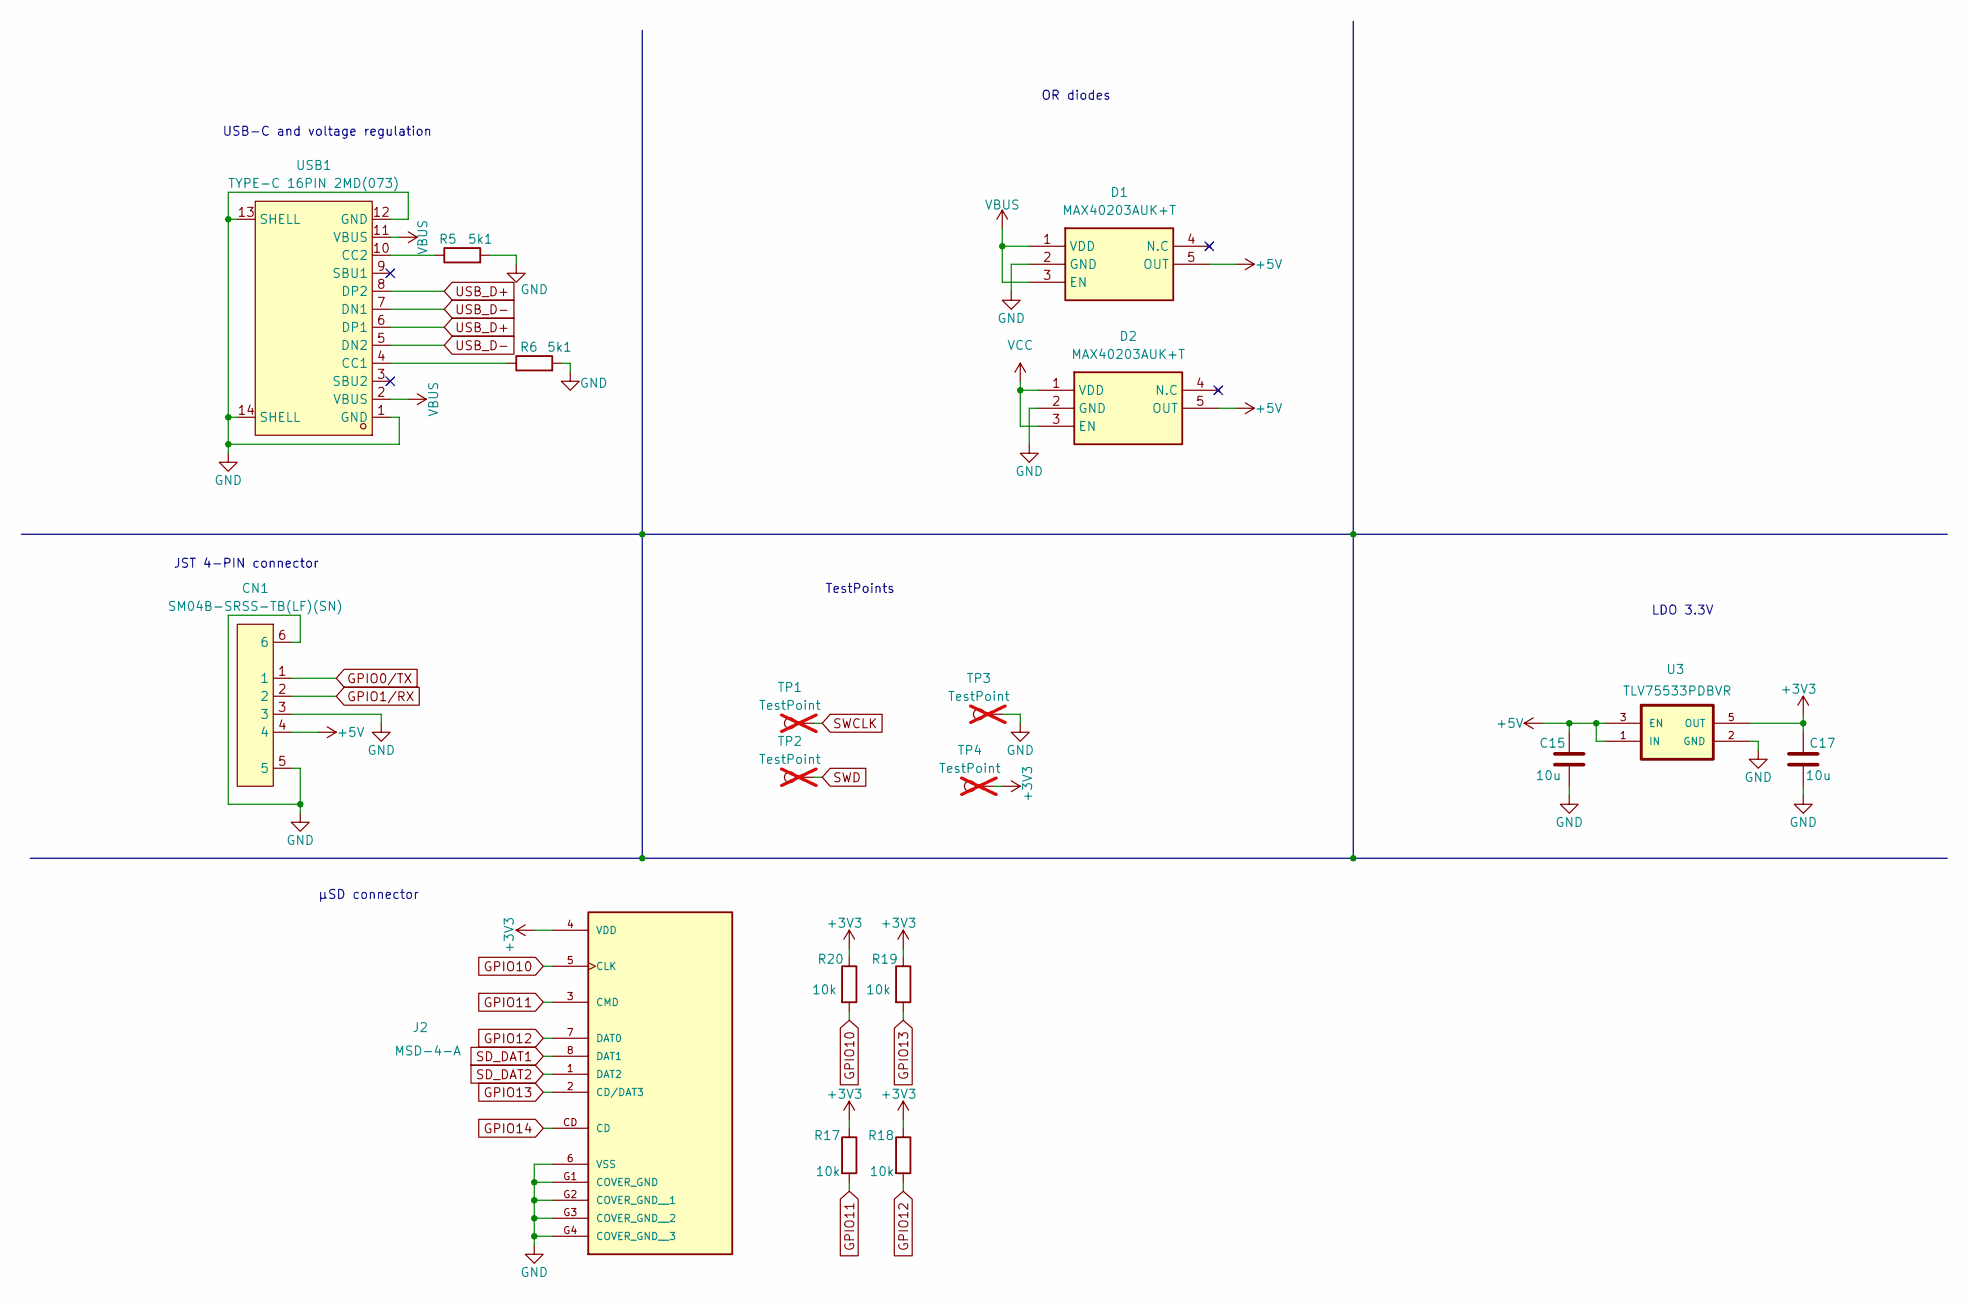
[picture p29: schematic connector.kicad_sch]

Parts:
C15, C17: 10u; C_0603_1608Metric; Manufacturer_Part_Number CL10A106MQ8NNNC
CN1: SM04B-SRSS-TB(LF)(SN); CONN-SMD_4P-P1.00_SM04B-SRSS-TB-LF-SN; Manufacturer Part SM04B-SRSS-TB(LF)(SN); LCSC Part Name 1x4P 间距:1mm 卧贴 系列:SH
D1, D2: MAX40203AUK+T; SOT95P280X145-5M; Mouser Part Number 700-MAX40203AUK+T
J2: MSD-4-A; CUI_MSD-4-A; PARTREV 1.0
R5, R6: 5k1; R_0603_1608Metric; Manufacturer_Part_Number ERA3AEB512V
R17, R18, R19, R20: 10k; R_0603_1608Metric; Manufacturer_Part_Number ERJUP3F1002V
TP1, TP2, TP3, TP4: TestPoint; TestPoint_Pad_D1.0mm; not fitted
U3: TLV75533PDBVR; SOT95P280X145-5N; Manufacturer_Part_Number TLV75533PDBVR
USB1: TYPE-C 16PIN 2MD(073); USB-C-SMD_TYPE-C-6PIN-2MD-073; Manufacturer Part TYPE-C 16PIN 2MD(073); LCSC Part Name Type-C 母 卧贴

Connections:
+3V3: C17.1, J2.4 (VDD), R17.1, R18.1, R19.1, R20.1, TP4.1 (1_1), U3.5 (OUT); also elsewhere on the board
+5V: C15.1, CN1.4, D1.5 (OUT), D2.5 (OUT), U3.1 (IN), U3.3 (EN); also elsewhere on the board
GND: C15.2, C17.2, CN1.3, CN1.5, CN1.6, D1.2 (GND), D2.2 (GND), J2.6 (VSS), J2.G1 (COVER_GND), J2.G2 (COVER_GND__1), J2.G3 (COVER_GND__2), J2.G4 (COVER_GND__3), R5.2, R6.2, TP3.1 (1_1), U3.2 (GND), USB1.1 (GND), USB1.12 (GND), USB1.13 (SHELL), USB1.14 (SHELL); also elsewhere on the board
GPIO0/TX: CN1.1; also elsewhere on the board
GPIO1/RX: CN1.2; also elsewhere on the board
GPIO10: J2.5 (CLK), R20.2; also elsewhere on the board
GPIO11: J2.3 (CMD), R17.2; also elsewhere on the board
GPIO12: J2.7 (DAT0), R18.2; also elsewhere on the board
GPIO13: J2.2 (CD/DAT3), R19.2; also elsewhere on the board
GPIO14: J2.CD
unnamed: R6.1, USB1.4 (CC1)
unnamed: R5.1, USB1.10 (CC2)
SD_DAT1: J2.8 (DAT1)
SD_DAT2: J2.1 (DAT2)
SWCLK: TP1.1 (1_1); also elsewhere on the board
SWD: TP2.1 (1_1); also elsewhere on the board
USB_D+: USB1.6 (DP1), USB1.8 (DP2); also elsewhere on the board
USB_D-: USB1.5 (DN2), USB1.7 (DN1); also elsewhere on the board
VBUS: D1.1 (VDD), D1.3 (EN), USB1.2 (VBUS), USB1.11 (VBUS)
VCC: D2.1 (VDD), D2.3 (EN)

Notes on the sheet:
USB-C and voltage regulation
OR diodes
TestPoints
JST 4-PIN connector
µSD connector
LDO 3.3V

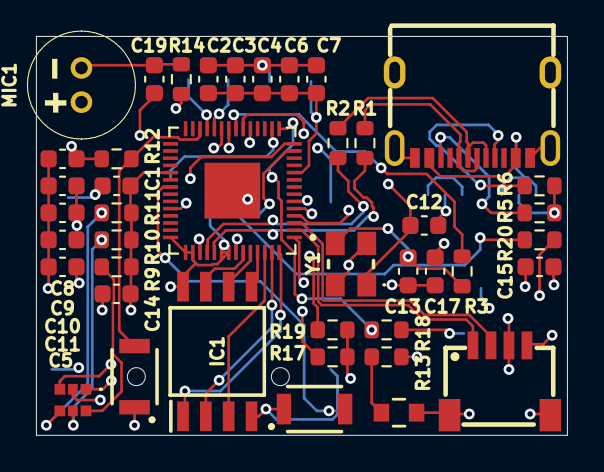
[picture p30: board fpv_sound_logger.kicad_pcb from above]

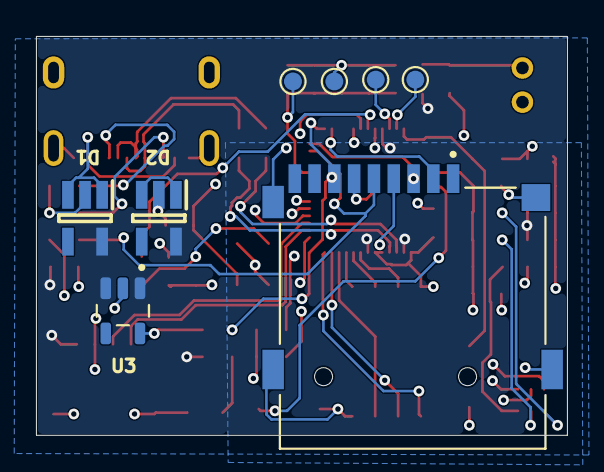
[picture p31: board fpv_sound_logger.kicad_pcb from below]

Board: 4 copper layers, 29.5 x 22.2 mm, 50 parts (8 on the bottom side), 40 nets.

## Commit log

2025-12-16 led indicator
2025-12-17 Add first iteration of PCB design on kicad
    [fpv_sound_logger.kicad_pcb, fpv_sound_logger.kicad_sch]
2025-12-17 PCB: add every components, now designing according to datasheets
    [fpv_sound_logger.kicad_sch]
2025-12-17 PCB: add JST connector, shottky diode, and few debugging
    [fpv_sound_logger.kicad_sch]
2025-12-18 PCB: finished schematic, started placing components, not decided yet for board dimensions
    [fpv_sound_logger.kicad_pcb, fpv_sound_logger.kicad_sch]
2025-12-18 PCB: started routing
    [fpv_sound_logger.kicad_pcb, fpv_sound_logger.kicad_sch]
2025-12-18 PCB: finised routing - Changed clearance from 0.2 to 0.15 in the net class settings. - Increased track width from 0.3 to 0.4 for improved signal integrity. - Added a new net class for POWER with patt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
    [fpv_sound_logger.kicad_pcb, fpv_sound_logger.kicad_sch]
2025-12-18 PCB: finishes on board design - DRC check - Placed text - add 3d files for 3d viewer
    [ABM8-272-T3.STEP, B3U-1000P.stp, DM3D-SF.stp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]
2026-04-24 Refactor code structure and remove redundant sections for improved readability and maintainability
    [LED_LTST-C171_LTO.step, LED_X01-GS08_VIS.step, MAX40203AUK+T.stp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]
2026-04-25 place new components and started routing for v2
    [connector.kicad_sch, fpv_sound_logger.kicad_pcb, mcu.kicad_sch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]
2026-05-15 Update component footprints and add manufacturer details in sensor schematic
    - Changed resistor footprint from R_0805 to R_0603 for multiple components.
    - Updated manufacturer part numbers, manufacturers, suppliers, and supplier parts for various components.
    - Added manufacturer and supplier information for OMRON components.
    - Removed outdated datasheet link and replaced with relevant part numbers for clarity.
    [connector.kicad_sch, fpv_sound_logger.kicad_pcb, mcu.kicad_sch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]
2026-05-16 Refactor code structure for improved readability and maintainability
    [POM-5038P-C3310-R.STEP, bom.csv, connector.kicad_sch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]
2026-05-17 Update PCB design and netlist for fpv_sound_logger
    - Added new segments and vias for microphone and GPIO connections in the PCB layout.
    - Removed redundant segments related to GPIO26_ADC0 and MIC1 in the PCB layout.
    - Updated active layer in the project file to improve visibility.
    - Modified visible layers in the project file for better layer management.
    - Adjusted netlist to include new connections for MIC1 and GPIO26_ADC0.
    - Changed manufacturer and supplier part numbers for components in the schematic.
    [fpv_sound_logger.csv, fpv_sound_logger.kicad_pcb, sensor.kicad_sch]
